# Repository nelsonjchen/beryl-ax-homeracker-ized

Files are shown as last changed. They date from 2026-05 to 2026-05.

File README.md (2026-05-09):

# Beryl AX HomeRacker Sleeve



[OpenSCAD](https://openscad.org/) source for adapting a
[GL.iNet Beryl AX](https://www.gl-inet.com/products/gl-mt3000/) holster to a
[HomeRacker](https://github.com/kellerlabs/homeracker) bar.

The model imports [`GL-INET-BERYL-AX-HOLSTER.stl`](reference/GL-INET-BERYL-AX-HOLSTER.stl)
at millimeter scale, adds a bottom-mounted HomeRacker sleeve, projects the
HomeRacker channel clearance up through the holster for cooling and optional
pin access, and includes a small side window for the device status light.

This is an OpenSCAD modification of the exported STL from
[`GL-INET-BERYL-AX-HOLSTER` by `DunknDonuts`](https://makerworld.com/en/models/428474-gl-inet-beryl-ax-holster),
not an edit of the upstream
[Onshape source CAD](https://cad.onshape.com/documents/4fd11188d706b52e56b15526/w/7970faa89563f7f57c9aa723/e/5b438853887219bc6ade6645).

## Status

This is currently in a rack I use for transporting a setup portably.

Published print profile:
[Beryl AX HomeRacker Sleeve on MakerWorld](https://makerworld.com/en/models/2776106-beryl-ax-homeracker-sleeve#profileId-3084506)

GitHub releases:
[beryl-ax-homeracker-ized releases](https://github.com/nelsonjchen/beryl-ax-homeracker-ized/releases)

## Preview

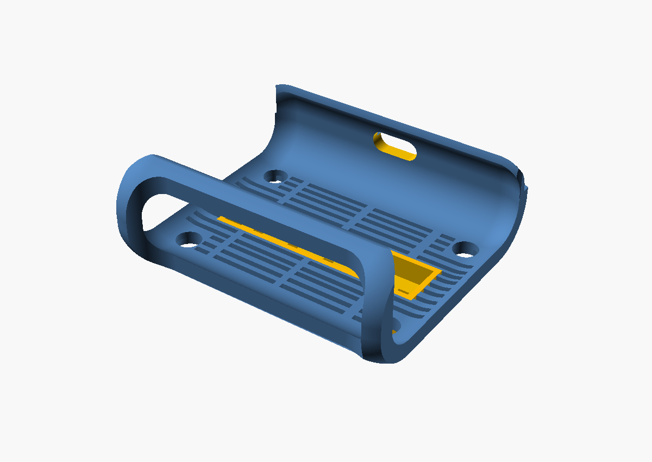
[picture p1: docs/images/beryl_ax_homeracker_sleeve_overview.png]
Beryl AX HomeRacker sleeve overview


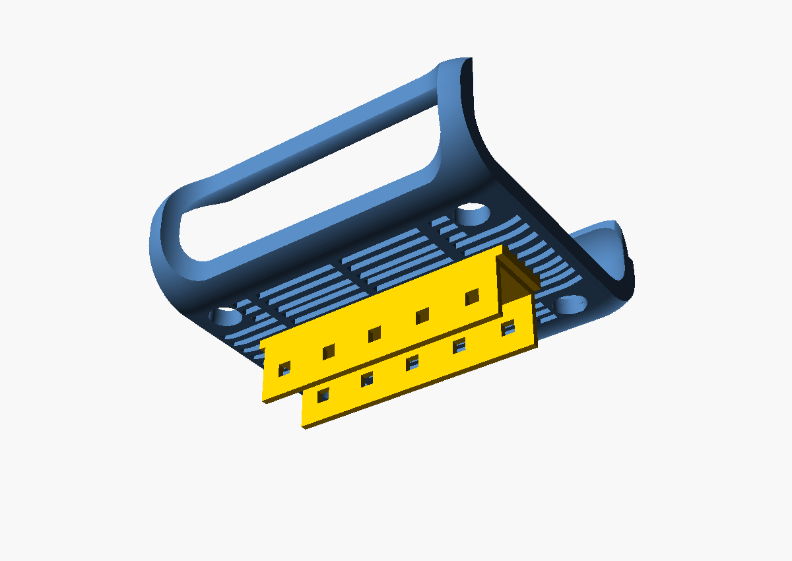
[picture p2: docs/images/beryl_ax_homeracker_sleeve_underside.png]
Underside view showing the HomeRacker sleeve graft


## Requirements

- `make`
- `uv`

OpenSCAD and SCAD library dependencies are installed and checked through
`scadm`.

## Quick Start

```sh
make sync
make install
make build
```

The default build writes:

- `renders/beryl_ax_homeracker_sleeve.stl`
- `renders/beryl_ax_homeracker_sleeve.png`

Curated README preview images are kept under `docs/images/`.

## GitHub Release STL

GitHub Actions renders `renders/beryl_ax_homeracker_sleeve.stl` on every push
and pull request, then uploads it as a workflow artifact.

To publish a release STL, push a version tag:

```sh
git tag v0.1.0
git push origin v0.1.0
```

The workflow creates or updates that GitHub Release and attaches the STL.

## Tooling

This repo uses `uv` for Python tooling and `scadm` for OpenSCAD setup and
dependency management.

- `make sync`: install Python tooling into `.venv/`
- `make install`: install OpenSCAD and SCAD dependencies through `uv run scadm install`
- `make check`: check the scadm-managed OpenSCAD/dependency install
- `make render`: render the complete modified sleeve model to STL
- `make png`: render a preview PNG
- `make build`: run setup and render both STL and PNG outputs
- `make clean`: remove generated render/export files

## Source Layout

Main OpenSCAD source:

```text
models/beryl_ax_homeracker_sleeve/parts/beryl_ax_homeracker_sleeve.scad
```

Reference mesh:

```text
reference/GL-INET-BERYL-AX-HOLSTER.stl
```

Upstream holster references:

- MakerWorld: [`GL-INET-BERYL-AX-HOLSTER` by `DunknDonuts`](https://makerworld.com/en/models/428474-gl-inet-beryl-ax-holster)
- Source CAD: [Onshape document](https://cad.onshape.com/documents/4fd11188d706b52e56b15526/w/7970faa89563f7f57c9aa723/e/5b438853887219bc6ade6645)

## Current Model

- Imports `reference/GL-INET-BERYL-AX-HOLSTER.stl`
- Scales the imported mesh by `1000` so it matches slicer dimensions
- Adds a 5-hole HomeRacker sleeve along the bottom
- Cuts matching 4 mm lock-pin holes through the sleeve side walls and roof
- Adds a top reinforcement frame around the sleeve channel opening
- Projects the HomeRacker channel clearance upward through the holster for cooling and optional lock-pin access
- Cuts a pill-shaped light window into the `+Y` side wall

## Key Parameters

The model is OpenSCAD Customizer-friendly. The most useful controls are listed
below. Defaults are shown as the SCAD expressions used in source.

| Parameter | Default | Purpose |
| --- | ---: | --- |
| `part_mode` | `0` | `0` complete model, `1` holster/reference only, `2` sleeve only |
| `sleeve_holes` | `5` | Number of HomeRacker lock-pin positions |
| `sleeve_rotation` | `90` | Sleeve orientation in degrees |
| `sleeve_wall` | `2` | Sleeve side-wall thickness |
| `sleeve_roof_thickness` | `2` | Sleeve roof thickness |
| `sleeve_embed_depth` | `0-2.8` | Vertical sleeve placement relative to the holster bottom |
| `top_reinforcement_wall` | `2` | Wall thickness of the reinforcement frame |
| `top_reinforcement_height` | `5+2.8` | Height of the reinforcement frame |
| `light_window_center` | `[0, 50, 20]` | Center point of the pill-shaped light window |
| `light_window_width` | `18` | Horizontal pill-window width |
| `light_window_height` | `8` | Pill-window height |
| `light_window_depth` | `18` | Cutter depth through the side wall |

HomeRacker conventions used here include 15 mm base units, 0.2 mm tolerance,
and 4 mm lock-pin holes.

## Release Checklist

Before publishing a release artifact:

```sh
make build
```

OpenSCAD should report the rendered model as manifold. Inspect
`renders/beryl_ax_homeracker_sleeve.png`, then use
`renders/beryl_ax_homeracker_sleeve.stl` as the export artifact.

## License

The HomeRacker sleeve and OpenSCAD adaptation work in this repository are
released under the Creative Commons Attribution-ShareAlike 4.0 International
license. See `LICENSE`.

The base Beryl AX holster design is
[`GL-INET-BERYL-AX-HOLSTER` by `DunknDonuts`](https://makerworld.com/en/models/428474-gl-inet-beryl-ax-holster).
See `NOTICE` for source attribution.

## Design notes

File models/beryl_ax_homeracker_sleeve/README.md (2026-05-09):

# Beryl AX HomeRacker Sleeve

Model-local source for the GL.iNet Beryl AX HomeRacker sleeve.

The OpenSCAD part imports the Beryl AX holster STL from `reference/`, adds a
bottom-mounted 5-hole HomeRacker sleeve, reinforces the top of the channel,
projects channel clearance upward through the holster for cooling and optional
lock-pin access, and cuts a small pill-shaped light window in the `+Y` side
wall.

The imported holster STL is based on
[`GL-INET-BERYL-AX-HOLSTER` by `DunknDonuts`](https://makerworld.com/en/models/428474-gl-inet-beryl-ax-holster).
This model modifies that exported STL through OpenSCAD; it does not edit the
upstream Onshape source CAD.

Build from the repository root:

```sh
make build
```

Main source:

```text
models/beryl_ax_homeracker_sleeve/parts/beryl_ax_homeracker_sleeve.scad
```

Generated STLs and preview PNGs are written under `renders/` and intentionally
ignored by Git. See the repository root README for tuning parameters and release
notes.

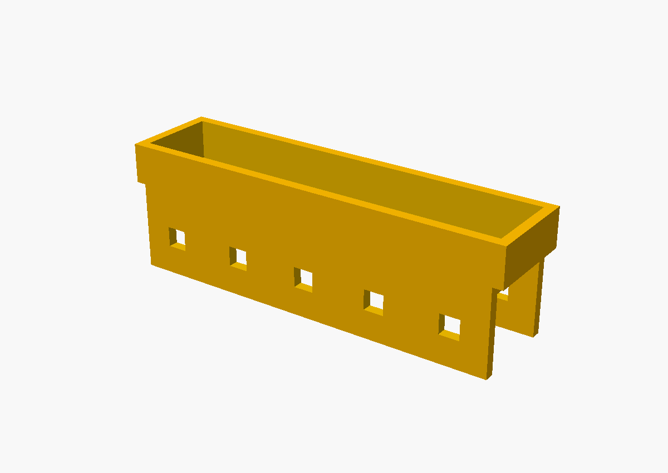
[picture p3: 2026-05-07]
docs/images/beryl_ax_homeracker_sleeve_detail.png

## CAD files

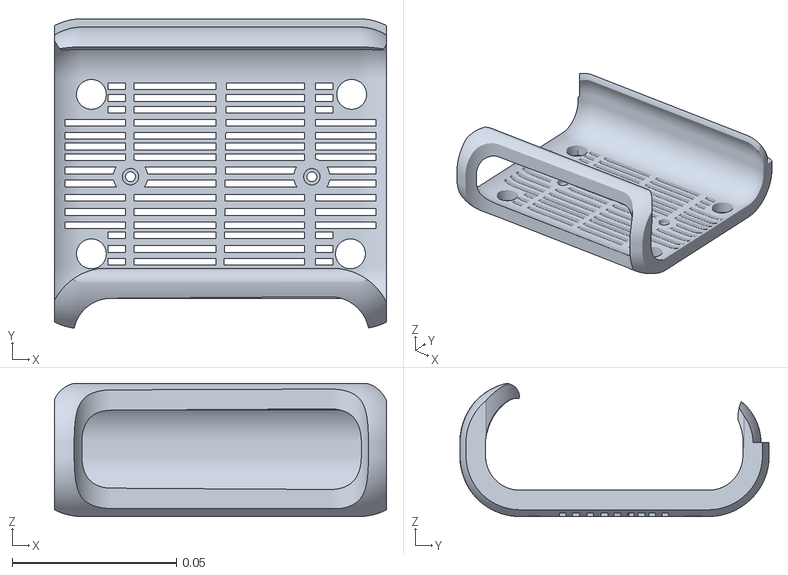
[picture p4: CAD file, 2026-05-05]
reference/GL-INET-BERYL-AX-HOLSTER.stl
0.101 x 0.0941 x 0.0405

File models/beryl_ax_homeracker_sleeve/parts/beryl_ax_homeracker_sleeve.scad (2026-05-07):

// GL.iNet Beryl AX HomeRacker sleeve source scaffold
//
// CC BY-SA 4.0

/* [Part] */
part_mode = 0; // [0:Complete mount,1:Reference STL only,2:HomeRacker sleeve only]

/* [Reference STL] */
reference_alpha = 1; // [0:0.05:1]
reference_scale = 1000; // [1:1:2000]
reference_translate = [0, 0, 0];
reference_rotate = [0, 0, 0];

/* [HomeRacker Sleeve] */
sleeve_holes = 5; // [1:1:8]
sleeve_rotation = 90; // [0,90]
sleeve_wall = 2; // [1.2:0.1:4]
sleeve_roof_thickness = 2; // [1.6:0.1:6]
sleeve_tolerance = 0.2; // [0:0.05:0.6]
sleeve_embed_depth = 0-2.8; // [0:0.1:4]
sleeve_offset = [0, 0];
top_reinforcement_wall = 2; // [0:0.1:6]
top_reinforcement_height = 5+2.8; // [0:0.1:8]
upward_channel_cut_enabled = true; // [false,true]
lockpin_holes_enabled = true; // [false,true]

/* [Light Window] */
light_window_enabled = true; // [false,true]
light_window_center = [0, 50, 20];
light_window_width = 18; // [4:0.1:40]
light_window_height = 8; // [2:0.1:20]
light_window_depth = 18; // [4:0.1:40]

/* [Debug] */
debug_colors = false; // [false,true]

/* [Hidden] */
$fn = 100;
EPSILON = 0.01;

// HomeRacker-compatible dimensions, mirrored locally so the model also
// compiles when opened directly in the OpenSCAD GUI.
BASE_UNIT = 15;
LOCKPIN_HOLE_SIDE_LENGTH = 4;
HR_YELLOW = "#f7b600";
REFERENCE_BLUE = "#4c78a8";

// Bounds measured from GL-INET-BERYL-AX-HOLSTER.stl after the default 1000x
// unit conversion. If the STL transform changes, adjust this bottom datum too.
BERYL_BOTTOM_Z = -2.5;
Z_INF = 200;

LOCKPIN_SIDE = LOCKPIN_HOLE_SIDE_LENGTH;
SLEEVE_INNER_SIDE = BASE_UNIT + sleeve_tolerance;
SLEEVE_OUTER_WIDTH = BASE_UNIT + 2 * sleeve_wall + sleeve_tolerance;
SLEEVE_LENGTH = sleeve_holes * BASE_UNIT - sleeve_tolerance;
SLEEVE_LOCKPIN_CENTER_Z = BASE_UNIT / 2 + sleeve_tolerance / 2;
SLEEVE_TOP_Z = SLEEVE_INNER_SIDE + sleeve_roof_thickness;
SLEEVE_MOUNT_Z = BERYL_BOTTOM_Z + sleeve_embed_depth - SLEEVE_TOP_Z;
TOP_REINFORCEMENT_OUTER_WIDTH = SLEEVE_INNER_SIDE + 2 * top_reinforcement_wall;
TOP_REINFORCEMENT_OUTER_LENGTH = SLEEVE_LENGTH + 2 * top_reinforcement_wall;
LIGHT_WINDOW_END_OFFSET = max((light_window_width - light_window_height) / 2, 0);

module centered_box(size) {
    cube(size, center = true);
}

module y_axis_cylinder(d, h) {
    rotate([90, 0, 0])
        cylinder(d = d, h = h, center = true);
}

module beryl_ax_homeracker_sleeve_source() {
    color(REFERENCE_BLUE, reference_alpha)
    translate(reference_translate)
    rotate(reference_rotate)
    scale(reference_scale)
        import("../../../reference/GL-INET-BERYL-AX-HOLSTER.stl", convexity = 10);
}

module side_lockpin_hole() {
    centered_box([SLEEVE_OUTER_WIDTH + EPSILON, LOCKPIN_SIDE, LOCKPIN_SIDE]);
}

module roof_lockpin_hole() {
    translate([0, 0, SLEEVE_INNER_SIDE + sleeve_roof_thickness / 2])
        centered_box([LOCKPIN_SIDE, LOCKPIN_SIDE, sleeve_roof_thickness + 2 * EPSILON]);
}

module local_lockpin_holes() {
    if (lockpin_holes_enabled) {
        for (hole = [0 : 1 : sleeve_holes - 1]) {
            local_y = (hole - (sleeve_holes - 1) / 2) * BASE_UNIT;

            translate([0, local_y, SLEEVE_LOCKPIN_CENTER_Z]) {
                side_lockpin_hole();
            }

            translate([0, local_y, 0])
                roof_lockpin_hole();
        }
    }
}

module local_upward_channel_cut() {
    if (upward_channel_cut_enabled) {
        translate([0, 0, SLEEVE_TOP_Z + Z_INF / 2])
            centered_box([SLEEVE_INNER_SIDE + 2 * EPSILON, SLEEVE_LENGTH + 2 * EPSILON, Z_INF]);
    }
}

module homeracker_sleeve_segment() {
    union() {
        for (wall_side = [-1, 1]) {
            translate([
                wall_side * (SLEEVE_INNER_SIDE / 2 + sleeve_wall / 2),
                0,
                SLEEVE_INNER_SIDE / 2
            ])
                centered_box([sleeve_wall, SLEEVE_LENGTH, SLEEVE_INNER_SIDE]);
        }

        translate([0, 0, SLEEVE_INNER_SIDE + sleeve_roof_thickness / 2])
            centered_box([SLEEVE_OUTER_WIDTH, SLEEVE_LENGTH, sleeve_roof_thickness]);

        if (top_reinforcement_wall > 0 && top_reinforcement_height > 0) {
            translate([0, 0, SLEEVE_TOP_Z + top_reinforcement_height / 2])
                centered_box([
                    TOP_REINFORCEMENT_OUTER_WIDTH,
                    TOP_REINFORCEMENT_OUTER_LENGTH,
                    top_reinforcement_height
                ]);
        }
    }
}

module homeracker_sleeve_positive() {
    color(HR_YELLOW)
    rotate([0, 0, sleeve_rotation])
        homeracker_sleeve_segment();
}

module homeracker_sleeve_holes() {
    rotate([0, 0, sleeve_rotation])
        union() {
            local_lockpin_holes();
            local_upward_channel_cut();
        }
}

module bottom_homeracker_sleeve_positive() {
    translate([sleeve_offset[0], sleeve_offset[1], SLEEVE_MOUNT_Z])
        homeracker_sleeve_positive();
}

module bottom_homeracker_sleeve_holes() {
    translate([sleeve_offset[0], sleeve_offset[1], SLEEVE_MOUNT_Z])
        homeracker_sleeve_holes();
}

module bottom_homeracker_sleeve() {
    difference() {
        bottom_homeracker_sleeve_positive();
        bottom_homeracker_sleeve_holes();
    }
}

module light_window_cut() {
    if (light_window_enabled) {
        translate(light_window_center)
            hull() {
                translate([-LIGHT_WINDOW_END_OFFSET, 0, 0])
                    y_axis_cylinder(d = light_window_height, h = light_window_depth);
                translate([LIGHT_WINDOW_END_OFFSET, 0, 0])
                    y_axis_cylinder(d = light_window_height, h = light_window_depth);
            }
    }
}

module beryl_ax_homeracker_sleeve_body() {
    difference() {
        beryl_ax_homeracker_sleeve_source();
        light_window_cut();
    }
}

module model() {
    assert(part_mode >= 0 && part_mode <= 2, "Part mode must be 0, 1, or 2.");
    assert(sleeve_holes > 0, "At least one sleeve hole is required.");
    assert(sleeve_rotation == 0 || sleeve_rotation == 90, "Sleeve rotation must be 0 or 90 degrees.");
    assert(sleeve_wall > 0, "Sleeve wall thickness must be positive.");
    assert(sleeve_roof_thickness > 0, "Sleeve roof thickness must be positive.");
//    assert(sleeve_embed_depth >= 0, "Sleeve embed depth cannot be negative.");
    assert(top_reinforcement_wall >= 0, "Top reinforcement wall cannot be negative.");
    assert(top_reinforcement_height >= 0, "Top reinforcement height cannot be negative.");
    assert(light_window_width > 0, "Light window width must be positive.");
    assert(light_window_height > 0, "Light window height must be positive.");
    assert(light_window_depth > 0, "Light window depth must be positive.");
    assert(light_window_width >= light_window_height, "Light window width must be at least its height.");
    assert(Z_INF > 100, "Z_INF must be tall enough to clear the source holster.");

    if (part_mode == 0) {
        difference() {
            union() {
                beryl_ax_homeracker_sleeve_body();
                bottom_homeracker_sleeve_positive();
            }

            bottom_homeracker_sleeve_holes();
        }
    } else if (part_mode == 1) {
        beryl_ax_homeracker_sleeve_body();
    } else if (part_mode == 2) {
        bottom_homeracker_sleeve();
    }
}

model();

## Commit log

2026-05-01 Initial HomeRacker Cisco AP mount
    [cisco_ap_homeracker_mount.scad]
2026-05-01 Skeletonize AP mount for airflow
    [cisco_ap_homeracker_mount.scad]
2026-05-01 little tighter
    [cisco_ap_homeracker_mount.scad]
2026-05-01 Add keyhole detent test matrix
    [cisco_ap_homeracker_mount.scad, keyhole_fit_coupon.scad]
2026-05-01 Move detent to slider seat edge
    [cisco_ap_homeracker_mount.scad, keyhole_fit_coupon.scad]
2026-05-01 Fix sleeve pin datum and detent coupons
    [cisco_ap_homeracker_mount.scad, keyhole_fit_coupon.scad]
2026-05-01 Remove redundant sleeve spine
    [cisco_ap_homeracker_mount.scad]
2026-05-01 Use bracket spine as sleeve roof
    [cisco_ap_homeracker_mount.scad]
2026-05-01 Shorten sleeve to end mount segments
    [cisco_ap_homeracker_mount.scad]
2026-05-01 Apply tested keyhole fit settings
    [cisco_ap_homeracker_mount.scad, keyhole_fit_coupon.scad]
2026-05-01 Document current fit and engrave model labels
    [cisco_ap_homeracker_mount.scad]
2026-05-01 Engrave repository slug on mount
    [cisco_ap_homeracker_mount.scad]
2026-05-01 Add two-piece clip variant
    [cisco_ap_homeracker_mount.scad]
2026-05-01 Refine clip labels and pair layout
    [cisco_ap_homeracker_mount.scad]
2026-05-01 Increase clip fit label size
    [cisco_ap_homeracker_mount.scad]
2026-05-04 Add sleeve gussets
    [cisco_ap_homeracker_mount.scad]
2026-05-04 Tune sleeve gussets
    [cisco_ap_homeracker_mount.scad]
2026-05-05 Add Ruckus HomeRacker mount prototype
    [cisco_ap_homeracker_mount.scad, keyhole_fit_coupon.scad, ruckus_ap_homeracker_sleeve.scad]
2026-05-05 Flatten and lower Ruckus prong strip
    [ruckus_ap_homeracker_sleeve.scad]
2026-05-05 Add drop gussets to Ruckus strip
    [ruckus_ap_homeracker_sleeve.scad]
2026-05-05 Make sleeve roof flush
    [ruckus_ap_homeracker_sleeve.scad]
2026-05-05 Shorten sleeve and tune gussets
    [ruckus_ap_homeracker_sleeve.scad]
2026-05-05 Create Beryl AX HomeRacker sleeve scaffold
    [GL-INET-BERYL-AX-HOLSTER.stl, beryl_ax_homeracker_sleeve.scad, ruckus_ap_homeracker_sleeve.scad]
2026-05-05 Add bottom HomeRacker sleeve graft
    [beryl_ax_homeracker_sleeve.scad]
2026-05-05 Tune sleeve embed depth
    [beryl_ax_homeracker_sleeve.scad]
2026-05-07 Add light window and tune sleeve reinforcement
    [beryl_ax_homeracker_sleeve.scad]
2026-05-09 Add STL build workflow
2026-05-09 Fix STL workflow OpenSCAD setup
2026-05-09 Pin HomeRacker OpenSCAD action tag
2026-05-09 Add Build STL status badge
